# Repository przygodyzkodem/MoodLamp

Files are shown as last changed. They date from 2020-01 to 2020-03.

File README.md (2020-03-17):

# MoodLamp

MoodLamp is an ESP8266 based WS2812B addressable LED controller. It's key features are:
- 55 different togglable light effects
- adjustable light color
- adjustable brightness
- quick on/off toggle
- easy configuration via captive portal
- minimalistic hardware design - cheap and easy to assemble and to install in your home

## Demo / Use Case Examples

Demo video (click to watch, don't forget to slap like :P ):
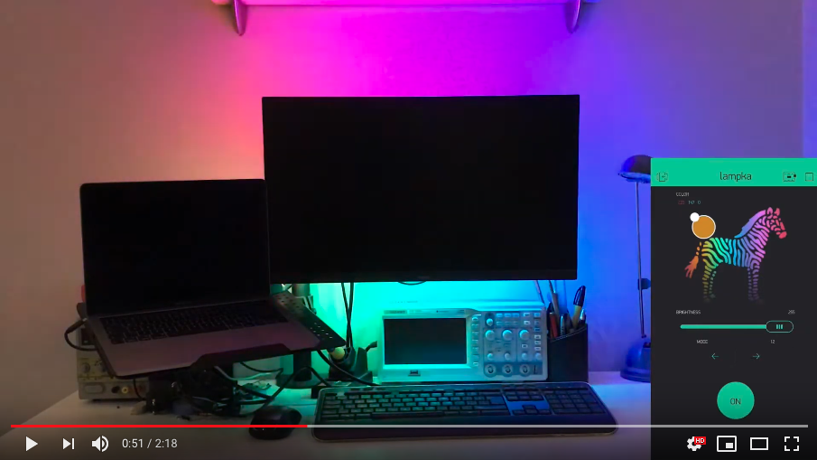
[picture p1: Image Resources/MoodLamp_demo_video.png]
MoodLamp Demo Video (https://www.youtube.com/watch?v=sJ2Bf1LhpAg)


Litophane lamp (gift for my lovely girlfriend):

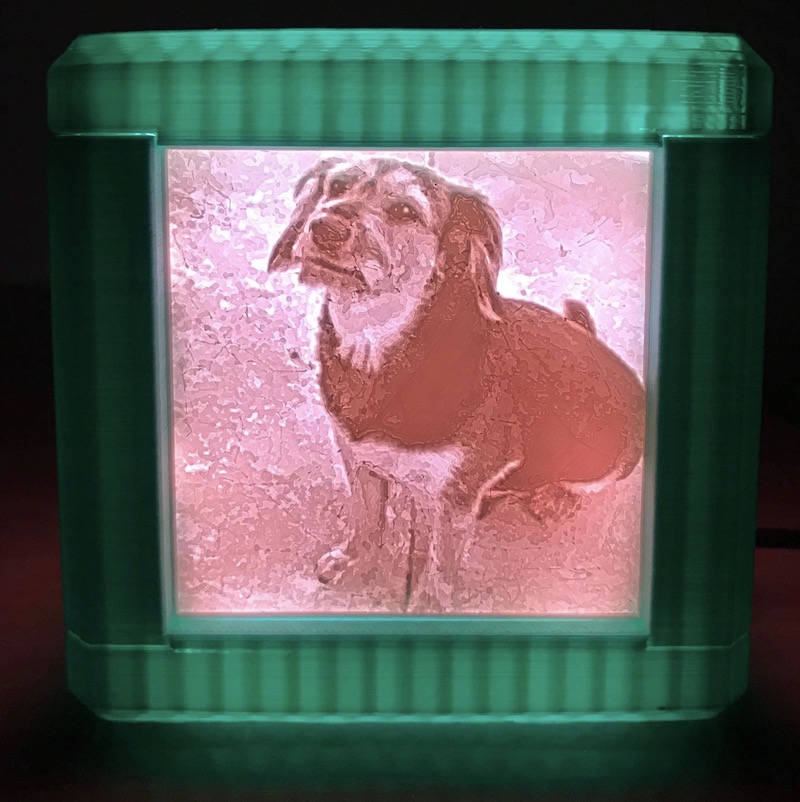
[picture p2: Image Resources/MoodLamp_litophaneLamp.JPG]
MoodLamp Litophane Lamp


3D Printer project kudos to GrkMangas from Thingiverse: [https://www.thingiverse.com/thing:2730082](https://www.thingiverse.com/thing:2730082)

## How to assemble your own Mood Lamp

In this repository you can find several types of resources. I plan to create few form factors of hardware and several software versions. The common thing for all of them will be the usage of ESP8266 module and Arduino code to drive addressable LEDs (e.g. WS2812B). To create your own Mood Lamp, please follow the steps listed below. Please note that each hyperlink will take you to another part of this repository which will contain another piece of documenation that will provide you with further details.

1. Pick your hardware version:
- you can build circuit out of Arduino modules based on Fritzing layout which you can find here
- you can assemble a NodeMCU shield with resources in folder: 
2. Select your software:
- currently only implementation using Blynk platform available: [LINK](https://github.com/przygodyzkodem/MoodLamp/tree/master/Software/Blynk)
3. Select proper power supply:
- all of the hardware designs will require power supply with 5V DC voltage
- to calculate the current required by your circuit, you can use the following equation: (60mA x N) + 120mA, where N is number of WS2812B diodes in your project
- please note, that if your project current requirement goes above few Amperes it is crossing a border where it becomes dangerous, consider splitting the project into few, separately powered modules
4. Install required software to control the Mood Lamp:
- currently it means installing Blynk app and properly configuring your project, check instructions in Software section for detailed instructions
5. Design your enclosure or use some ideas from repository.

## Plans / ToDo:

- add documentation for Fritzing layout / basic connections on breadboard
- add documentation for Blynk software implementation
- add documentation for Hardware version (NodeMCU shield)
- design a 3D printed enclosure for NodeMCU + hardware shield

## Contributing

If you find any errors/bugs/problems with either hardware or software, please create a new issue in this repository to let me know. If you have an idea for a new feature or hardware or software variant, please also use Issues section so we can discuss it.

## License
MoodLamp project is available under the MIT License. See the [LICENSE](https://github.com/przygodyzkodem/MoodLamp/blob/master/LICENSE) file for more info.

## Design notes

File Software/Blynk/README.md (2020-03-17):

# Blynk platform Software Version

This software variant utilizes Blynk platform to allow easy installation, configuration and usage of your MoodLamp device. Best choice for beginners or if you don't plan to create bigger smart home system.

## Features
- easy installation and configuration
- 55 different togglable light effects
- adjust light color
- adjust brightness
- quick on/off toggle

## How to install & configure

### Arduino Software

1. Install Arduino (I'm currently using version 1.8.10)
2. Launch Sketch file (.ino file format) and open Arduino Preferences window.
3. Enter `https://arduino.esp8266.com/stable/package_esp8266com_index.json` into the Additional Board Manager URLs field. You can add multiple URLs, separating them with commas.
4. Open Boards Manager from Tools > Board menu and install esp8266 platform (and don't forget to select your ESP8266 board from Tools > Board menu after installation).
4. Install required 3rd party libraries or copy them from this repository's libraries folder (recommended - you will avoid problems with library version compatibility).
5. Enter correct value that represents number of NeoPixel leds you want to drive in line:
`#define PIXEL_COUNT 36`
6. (Optional) enter your WiFi network SSID and password and Blynk auth token to speed up integration process.
7. Flash your Arduino software to NodeMCU (note: you should avoid connecting long LED strips to your computer USB port to prevent high current drain).

### Mobile app

1. Install Blynk mobile app (available for Android and iOS devices)
2. Create account / sign in into Blynk app
3. Run QR code scanner in Blynk app (QR Code icon on navigation bar) and scan code below to clone project configuration:
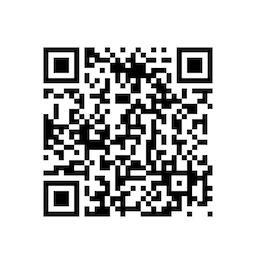
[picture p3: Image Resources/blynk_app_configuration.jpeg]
Clone Blynk Project Configuration
[]

That's it, your mobile app for controlling MoodLamp device is ready! :) Now for the final step!

### Integration

If you have already successfully flashed Arduino software and configured Blynk app you're ready to integrate them together, so you can control your device with Blynk app. If you've completed step 6. from Arduino Software installation tutorial, you can skip all of this and go directly to Blynk app to control your MoodLamp! In other case read along to complete the integration.

We'll start with getting Blynk Auth Token. Open your Blynk app and go to project settings (nut icon on navigation bar). Here you will see a blue text consisting of 32 letters and digits. It is labeled as Auth Token. If you tap it, it will be copied to the clipboard of your device. We will need it in the next step.

Power up your MoodLamp device if you haven't already and go to network settings on your mobile device. On the list of available WiFi networks, you should be able to see the network broadcasted by your MoodLamp device. By default it should be named "MoodLamp" if you didn't change it in Arduino code. Click it as if you wanted to connect to it. The Captive Portal should open with fields for SSID (network name) and Password of WiFi network you want your MoodLamp to connect to (note: it must be 2.4GHz WiFi network). Third text field is for Auth Token that we copied in previous step. Paste it here and save the data. Your MoodLamp will restart and connect to the WiFi network and Blynk service and should be ready to be controlled by the mobile app. Launch Blynk and try it out! :) 

## Plans / ToDo
- Add error handling (use first NeoPixel in strip to signal common types of errors to the user)
- Improve documentation styling
- Add some screenshots to the README file

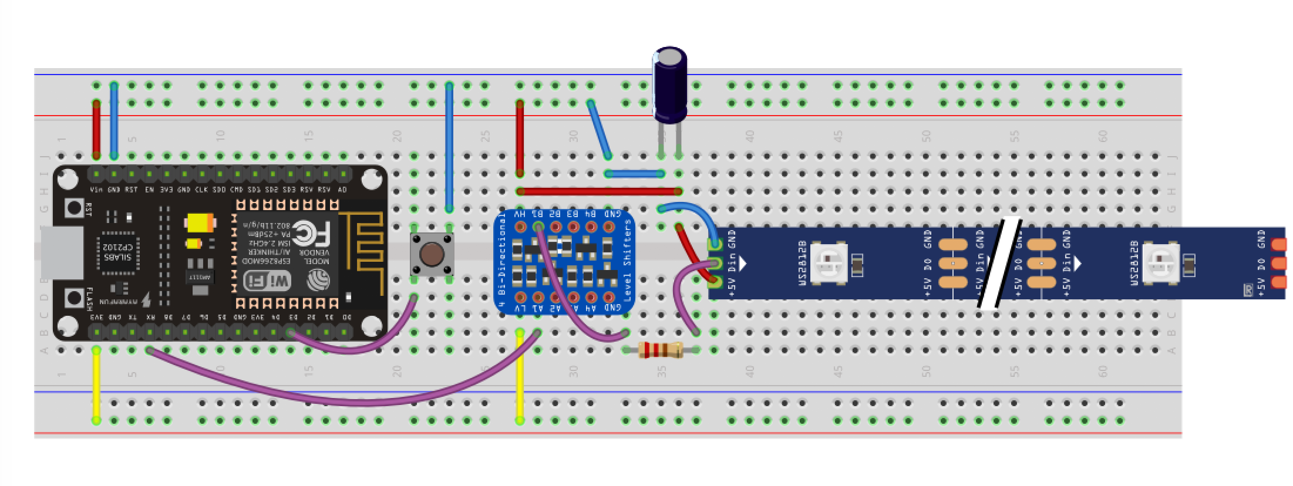
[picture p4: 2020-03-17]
Image Resources/Fritzing_NodeMCU+LevelShifter+Reset+Strip.png

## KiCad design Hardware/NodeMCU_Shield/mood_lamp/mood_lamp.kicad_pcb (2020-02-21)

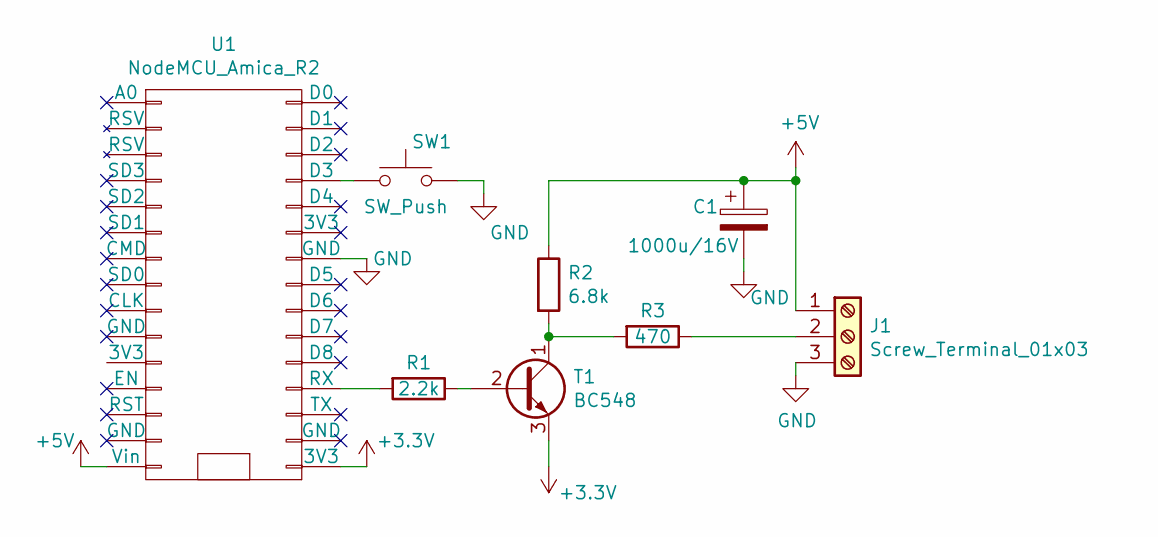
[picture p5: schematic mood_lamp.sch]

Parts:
C1: 1000u/16V; CP_Radial_D10.0mm_P7.50mm
J1: Screw_Terminal_01x03; TerminalBlock_bornier-3_P5.08mm
R1: 2.2k; R_Axial_DIN0207_L6.3mm_D2.5mm_P7.62mm_Horizontal
R2: 6.8k; R_Axial_DIN0207_L6.3mm_D2.5mm_P7.62mm_Horizontal
R3: 470; R_Axial_DIN0207_L6.3mm_D2.5mm_P7.62mm_Horizontal
SW1: SW_Push; SW_PUSH_6mm_H5mm
T1: BC548; TO-92_Inline
U1: NodeMCU_Amica_R2

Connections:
+3V3: T1.3 (E), U1.16 (3V3)
+5V: C1.1, J1.1, R2.1, U1.15 (Vin)
GND: C1.2, J1.3, SW1.2, U1.24 (GND)
unnamed: J1.2, R3.1
unnamed: R1.1, T1.2 (B)
unnamed: R1.2, U1.19 (RX)
unnamed: R2.2, R3.2, T1.1 (C)
unnamed: SW1.1, U1.27 (D3)

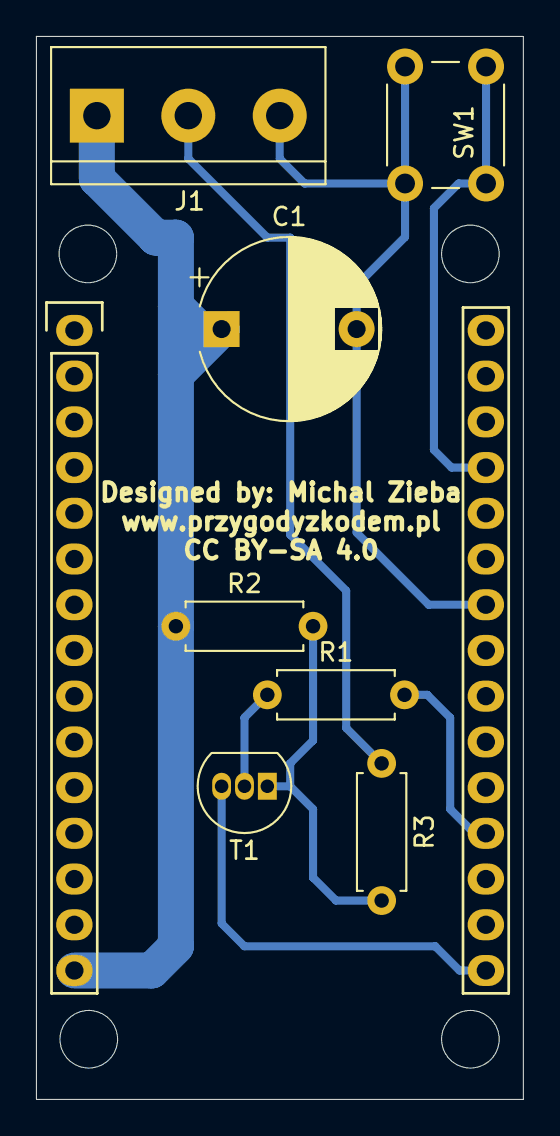
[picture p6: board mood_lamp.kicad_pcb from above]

Board: 2 copper layers, 27.1 x 59.1 mm, 8 parts (0 on the bottom side), 8 nets.

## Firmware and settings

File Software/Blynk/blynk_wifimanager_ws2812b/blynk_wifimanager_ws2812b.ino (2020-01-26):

/* Comment this out to disable prints and save space */
#define BLYNK_PRINT Serial

#define LED_PIN D9
#define RESET_BUTTON_PIN D3

#define PIXEL_COUNT 36
#define BLYNK_TOKEN_LENGTH 33

#include <ESP8266WiFi.h>
#include <BlynkSimpleEsp8266.h>
#include <WiFiManager.h>
#include <EEPROM.h>
#include <WS2812FX.h>


// You should get Auth Token in the Blynk App.
// Go to the Project Settings (nut icon).
char blynk_token[] = "";

// Your WiFi credentials.
// Set password to "" for open networks.
char ssid[] = "wifi_name";
char pass[] = "wifi_password";

WS2812FX strip = WS2812FX(PIXEL_COUNT, LED_PIN, NEO_GRB + NEO_KHZ800);
WiFiManager wifiManager;
WiFiManagerParameter blynkToken("Blynk", "blynk token", blynk_token, BLYNK_TOKEN_LENGTH);


int mode = 0;
int red = 255;
int green = 200;
int blue = 170;
int brightness = 255;

void initializeLedStrip() {
  strip.init();
  strip.setBrightness(brightness);
  strip.setColor(red, green, blue);
  strip.setSpeed(200);
  strip.setMode(mode);
  strip.start();
  strip.service();
}

void connectWiFi() {
  //wifiManager.resetSettings(); //WiFiManager remembers previously connected APs
  wifiManager.addParameter(&blynkToken);
  wifiManager.autoConnect("Lampka");
}

void setup()
{
  // Debug console
  Serial.begin(9600);
  delay(100);
  pinMode(D4, OUTPUT);
  digitalWrite(D4, HIGH);

  pinMode(RESET_BUTTON_PIN, INPUT_PULLUP);

  EEPROM.begin(512);
  char blynkTokenEEPROM[BLYNK_TOKEN_LENGTH] = "";
  EEPROM.get(0, blynkTokenEEPROM);
  Serial.print("Blynk token read from EEPROM: ");
  Serial.println(blynkTokenEEPROM);
  Serial.println("Blynk token from WebPanel: ");
  Serial.print(blynkToken.getValue());
  Serial.println();
  
  initializeLedStrip();
  connectWiFi();
  
  if (blynkToken.getValue()[0] != blynk_token[0]) {
    Serial.println("Using Blynk token from WebPanel");
    Blynk.config(blynkToken.getValue());  
  } else {
    Serial.print("Using Blynk Token from EEPROM");
    Blynk.config(blynkTokenEEPROM);
  }
  
  if(!Blynk.connect()) {
    Serial.println("Blynk connection timed out.");
  }

  if (blynkToken.getValue()[0] != blynk_token[0]) {
    for (int i = 0; i < BLYNK_TOKEN_LENGTH; i++) {
      blynkTokenEEPROM[i] = blynkToken.getValue()[i];
    }
    Serial.print("Overwriting blynk token in EEPROM: ");
    Serial.println(blynkTokenEEPROM);
    EEPROM.put(0, blynkTokenEEPROM);
    EEPROM.commit();
  }

  //Send to Blynk current lamp state so app reflects it correctly
  Blynk.virtualWrite(V1, red, green, blue);
  Blynk.virtualWrite(V2, brightness);
  Blynk.virtualWrite(V3, LOW);
  Blynk.virtualWrite(V4, mode); 
}

void loop()
{
  Blynk.run();
  strip.service();
  handleResetButton();
}

void handleResetButton() {
  int resetButtonState = digitalRead(RESET_BUTTON_PIN);
  if (resetButtonState == LOW) {
    Serial.println("RESET PRESSED");
    wifiManager.resetSettings();
    delay(1000);
    ESP.restart();
  }
}

BLYNK_WRITE(V1) {
  red = param[0].asInt();
  green = param[1].asInt();
  blue = param[2].asInt();
  strip.setColor(red, green, blue);
}

BLYNK_WRITE(V2) {
  brightness = param.asInt();
  strip.setBrightness(brightness);
}


// This function will be called every time button Widget
// in Blynk app writes values to the Virtual Pin V3
BLYNK_WRITE(V3) {
 int pinValue = param.asInt(); // Assigning incoming value from pin V3 to a variable
 if (pinValue == 1) {
    strip.stop();
  } else {
    strip.start();
  }
}

BLYNK_WRITE(V4) {
  mode = param.asInt();
  strip.setMode(mode);
}

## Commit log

2020-01-02 Fixed bug with not turning on light before connecting to WiFi. Started to divide code from setup into smaller functions.
    [blynk_wifimanager_ws2812b.ino]
2020-01-25 Fixed problem with rewriting Blynk token to EEPROM (incorrect value was saved to EEPROM on 2nd and each next usage of WiFiManager captive portal).
    [blynk_wifimanager_ws2812b.ino]
2020-01-25 Disabled blue LED built into ESP8266 module.
2020-01-25 Moved Blynk token length to constant value definition. Added sending correct MoodLamp state to Blynk so app reflects it on lamp restart.
    [blynk_wifimanager_ws2812b.ino]
2020-01-26 Added basic reset button action - resetting WiFiManager to allow easier reconnecting to another WiFiNetwork or entering another Blynk Token. TODO: Change reset button to be triggered by long press ac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
    [blynk_wifimanager_ws2812b.ino]
2020-01-26 Changed reset button pin assignment to make PCB prototyping easier. Added KiCAD project with NodeMCU shield schematic and PCB design
    [mood_lamp.kicad_pcb, mood_lamp.sch]
2020-01-26 Added Fritzing layout for design utilizing Logic Level Shifter module.
    [moodlamp_level_shifter_module.fzz]
2020-02-21 Updated fritzing layouts. Fixed some issues with PCB design. Generated Gerber files.
    [mood_lamp-B_Cu.gbr, mood_lamp-B_Mask.gbr, mood_lamp-B_Paste.gbr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]
2020-03-17 Add instructions for assembling Blynk based software variant.

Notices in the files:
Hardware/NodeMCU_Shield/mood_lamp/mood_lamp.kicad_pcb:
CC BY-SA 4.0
